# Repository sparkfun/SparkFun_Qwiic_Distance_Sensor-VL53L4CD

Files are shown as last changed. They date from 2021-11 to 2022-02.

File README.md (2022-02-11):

SparkFun Distance Sensor - VL53L4CD (Qwiic)
========================================

SparkFun Distance Sensor - VL53L4CD (Qwiic) (https://www.sparkfun.com/products/18993)

[*SparkFun Distance Sensor - VL53L4CD (Qwiic) (SEN-18993)*](https://www.sparkfun.com/products/18993)

This SparkFun Distance Sensor Breakout utilizes the VL53L4CD next generation ToF (Time of Flight) sensor module to give you the highly accurate measurements at short ranges for its size. The VL53L4CD from STMicroelectronics uses a VCSEL (Vertical Cavity Surface Emitting Laser) to emit an infrared laser to time the reflection to the target. That means that you will be able to measure the distance to an object from 1mm to 1300mm away with millimeter resolution! To make it even easier to get your readings, all communication is enacted exclusively via I<sup>2</sup>C, utilizing our handy Qwiic system so no soldering is required to connect it to the rest of your system. However, we still have broken out 0.1”-spaced pins in case you prefer to use a breadboard.

Each VL53L4CD sensor features a precision to be 1mm with an accuracy around +/-7mm (white target: 88%, indoor, no infrared) and a minimum read distance of this sensor is 1mm. The field of view for this little breakout has a typical full field of view of 18° with a read rate of up to 100Hz. Make sure to power this board appropriately since it will need 2.6V-3.5V to operate. Lastly, please be sure to remove the protective sticker on the VL53L1X before use otherwise it will, most assuredly, throw off your readings.

**Note:** This is a [CLASS 1](http://en.wikipedia.org/wiki/Laser_safety#Class_1) LASER PRODUCT CLASSIFIED IEC 60825-1 2014.

Repository Contents
-------------------

* **/Hardware** - Eagle design files (.brd, .sch)
* **/Production** - Production panel files (.brd)

Documentation
--------------
* **[Arduino Library](https://github.com/sparkfun/SparkFun_VL53L1X_Arduino_Library)** -  Arduino library for the VL53L1X and VL53L4CD.
* **[VL53L1X Python Package](https://github.com/sparkfun/Qwiic_VL53L1X_Py)** - Python package for the VL53L1X and VL53L4CD.
  * **[ReadtheDocs Documentation](https://qwiic-vl53l1x-py.readthedocs.io/en/latest/)**
* **[Hookup Guide](https://learn.sparkfun.com/tutorials/qwiic-distance-sensor-vl53l1x-vl53l4cd-hookup-guide)** - Basic hookup guide for the VL53L1X and VL53L4CD.

Product Versions
----------------
* [SEN-18993](https://www.sparkfun.com/products/18993) - Initial Release

Version History
---------------
* v1.0 - Initial Release 

License Information
-------------------

This product is _**open source**_! 

Please review the LICENSE.md file for license information. 

If you have any questions or concerns on licensing, please contact technical support on our [SparkFun forums](https://forum.sparkfun.com/viewforum.php?f=152).

Distributed as-is; no warranty is given.

- Your friends at SparkFun.

_<COLLABORATION CREDIT>_

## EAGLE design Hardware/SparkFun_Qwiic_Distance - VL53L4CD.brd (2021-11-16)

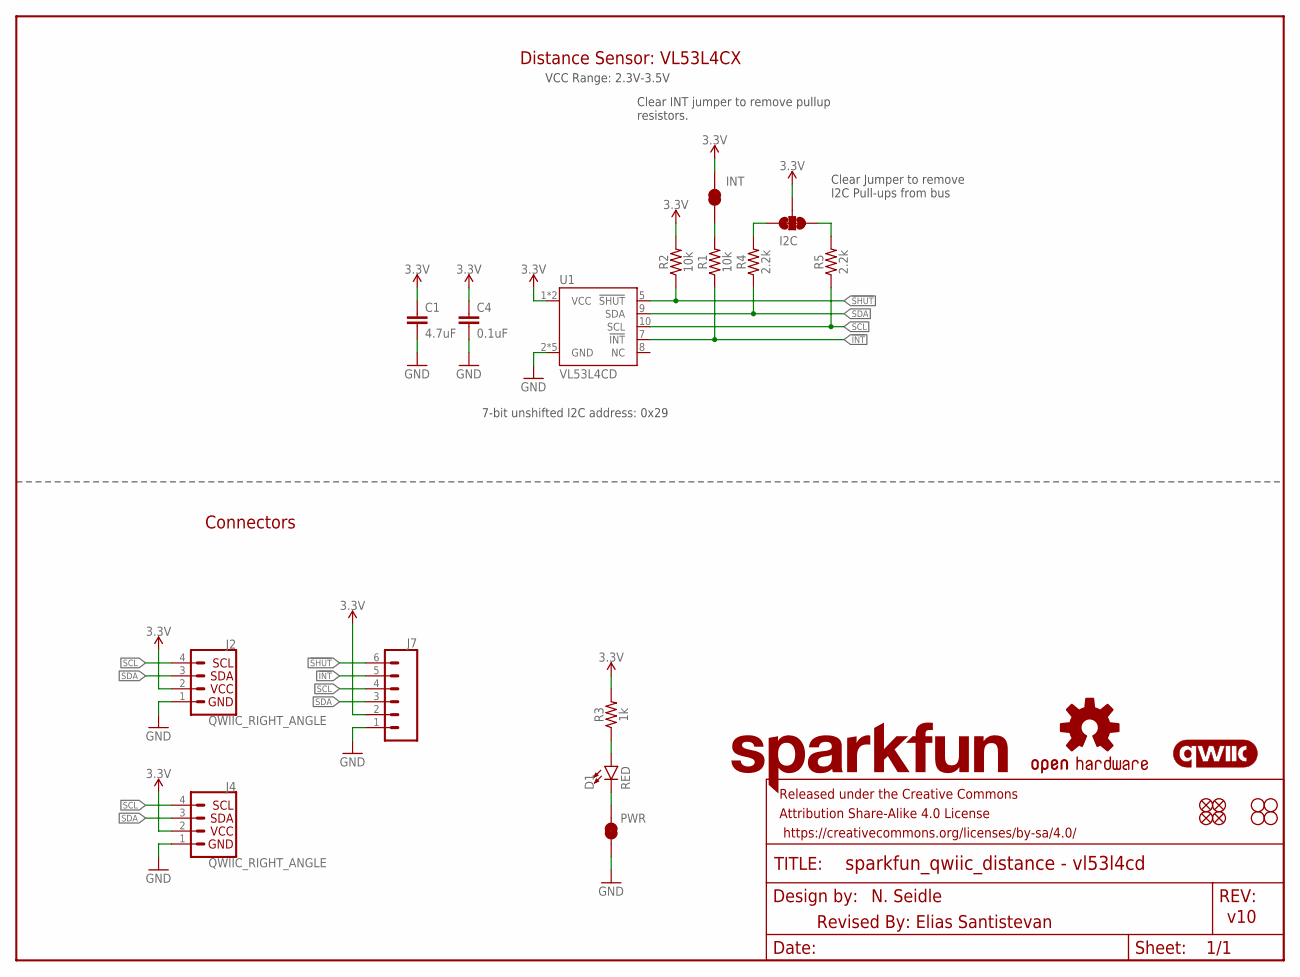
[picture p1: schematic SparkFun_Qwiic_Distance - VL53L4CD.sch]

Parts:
C1: 4.7uF; 0603
C4: 0.1uF; 0603
D1: RED; LED-0603
FRAME1: FRAME-LETTER; CREATIVE_COMMONS
I2C: JUMPER-SMT_3_2-NC_TRACE_SILK; SMT-JUMPER_3_2-NC_TRACE_SILK
J2, J4: QWIIC_RIGHT_ANGLE; JST04_1MM_RA
J7: CONN_06NO_SILK_NO_POP; 1X06_NO_SILK
JP1, JP2, JP5, JP6: FIDUCIALUFIDUCIAL; MICRO-FIDUCIAL
JP3, JP4, JP7, JP8: STAND-OFF
JP9: INT; SMT-JUMPER_2_NC_TRACE_SILK
LOGO1: OSHW-LOGOMINI; OSHW-LOGO-MINI
LOGO2: SFE_LOGO_NAME.1_INCH; SFE_LOGO_NAME_.1
LOGO3: QWIIC_LOGO_4MM; QWIIC_4MM
PWR: INT; SMT-JUMPER_2_NC_TRACE_SILK
R1, R2: 10k; 0603
R3: 1k; 0603
R4, R5: 2.2k; 0603
U1: VL53L4CD

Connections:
3.3V: C1.1, C4.1, I2C.2, J2.2, J4.2, J7.2, JP9.2, R2.2, R3.2, U1.1 (VCC), U1.11 (VCC)
!INT: J7.5, R1.1, U1.7 (!INT)
!SHUT: J7.6, R2.1, U1.5 (!SHUT)
GND: C1.2, C4.2, J2.1, J4.1, J7.1, PWR.1, U1.2 (GND), U1.3 (GND), U1.4 (GND), U1.6 (GND), U1.12 (GND)
unnamed: I2C.1, R5.2
unnamed: I2C.3, R4.2
unnamed: D1.A, R3.1
unnamed: JP9.1, R1.2
unnamed: D1.C, PWR.2
SCL: J2.4, J4.4, J7.4, R5.1, U1.10 (SCL)
SDA: J2.3, J4.3, J7.3, R4.1, U1.9 (SDA)

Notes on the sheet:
N. Seidle
v10
7-bit unshifted I2C address: 0x29
Clear Jumper to remove I2C Pull-ups from bus
Clear INT jumper to remove pullup resistors.
Connectors
Distance Sensor: VL53L4CX
VCC Range: 2.3V-3.5V
Revised By: Elias Santistevan

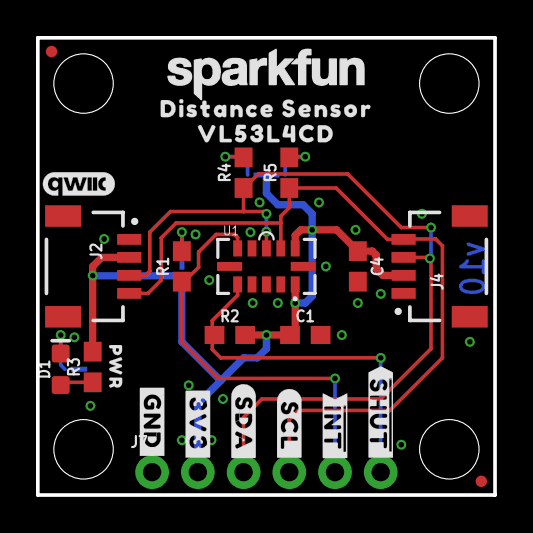
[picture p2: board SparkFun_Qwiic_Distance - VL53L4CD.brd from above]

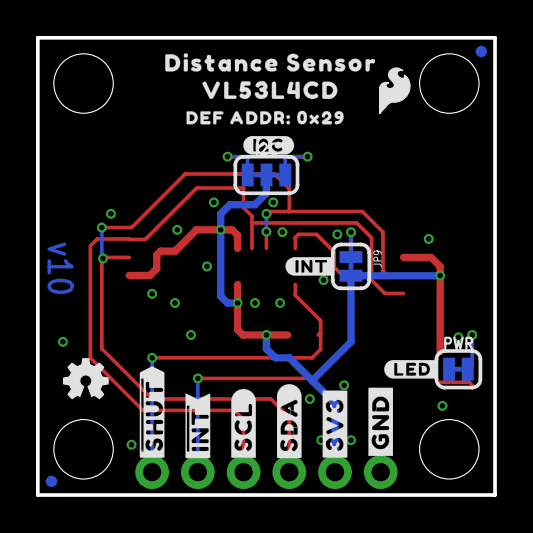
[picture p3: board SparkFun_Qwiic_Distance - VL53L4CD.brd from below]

Board: 2 copper layers, 25.4 x 25.4 mm, 50 parts (20 on the bottom side), 11 nets.

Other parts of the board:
U$1, U$12: ##INT##7
U$2, U$13: ##SHUT##6
U$3, U$14: #3V3#1
U$4, U$15: #GND#0
U$5: #I2C#56
U$6, U$16: #SCL#4
U$7, U$17: #SDA#5
U$8, U$18: DISTANCE_SENSOR8
U$9, U$24: VL53L4CD0
U$10: #LED#54
U$11: #INT#55
U$20: DEF_ADDR#54
U$21: 0X2955
U$22: SFE_LOGO_FLAME_.1
U$23: PWR55

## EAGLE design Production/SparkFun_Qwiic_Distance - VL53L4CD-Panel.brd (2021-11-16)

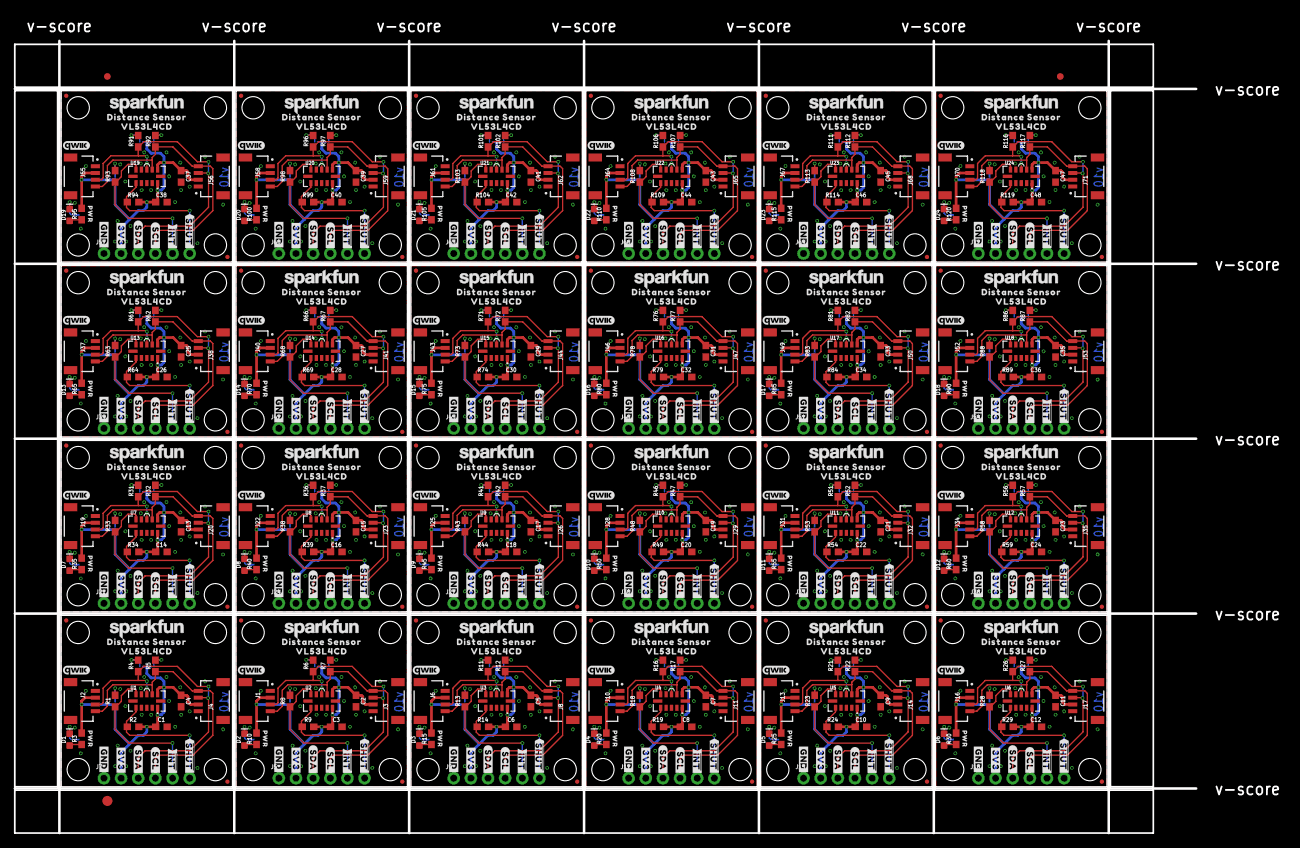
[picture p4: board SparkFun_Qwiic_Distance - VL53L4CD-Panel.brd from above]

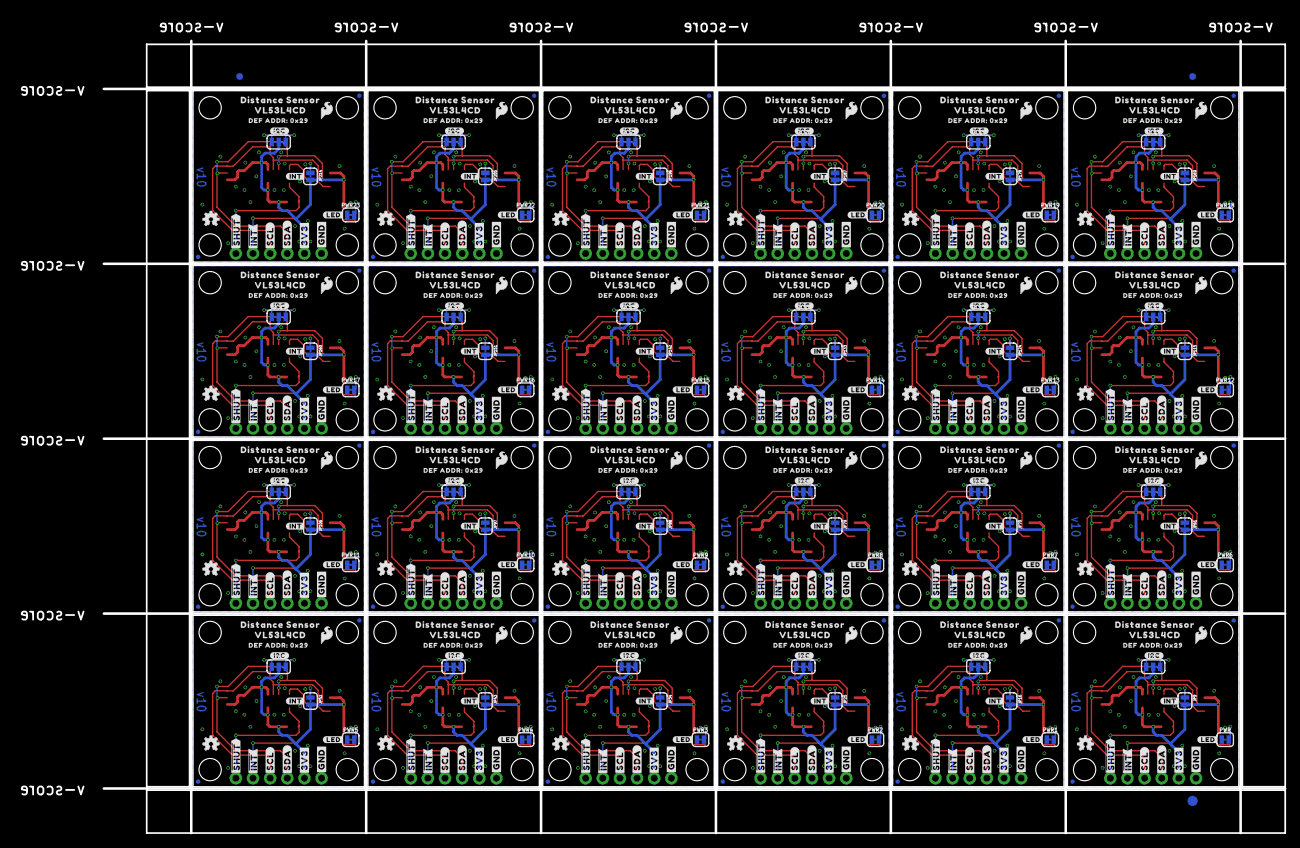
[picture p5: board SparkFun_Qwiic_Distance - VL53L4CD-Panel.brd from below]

Board: 2 copper layers, 175.0 x 117.3 mm, 1182 parts (483 on the bottom side), 264 nets.

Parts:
C1, C3, C6, C8, C10, C12, C14, C16, C18, C20, C22, C24, C26, C28, C30, C32, C34, C36, C38, C40, C42, C44, C46, C48: 4.7uF; 0603
C2, C4, C5, C7, C9, C11, C13, C15, C17, C19, C21, C23, C25, C27, C29, C31, C33, C35, C37, C39, C41, C43, C45, C47: 0.1uF; 0603
D1, D2, D3, D4, D5, D6, D7, D8, D9, D10, D11, D12, D13, D14, D15, D16, D17, D18, D19, D20, D21, D22, D23, D24: RED; LED-0603
E$1, E$2, E$3, E$4: FIDUCIAL-1X2
E$5, E$6: FIDUCIAL-1.5X3
I2C, I2C1, I2C2, I2C3, I2C4, I2C5, I2C6, I2C7, I2C8, I2C9, I2C10, I2C11, I2C12, I2C13, I2C14, I2C15, I2C16, I2C17, I2C18, I2C19, I2C20, I2C21, I2C22, I2C23: JUMPER-SMT_3_2-NC_TRACE_SILK; SMT-JUMPER_3_2-NC_TRACE_SILK
J1, J2, J3, J4, J6, J8, J10, J11, J13, J14, J16, J17, J19, J20, J22, J23, J25, J26, J28, J29, J31, J32, J34, J35, J37, J38, J40, J41, J43, J44, J46, J47, J49, J50, J52, J53, J55, J56, J58, J59, J61, J62, J64, J65, J67, J68, J70, J71: QWIIC_RIGHT_ANGLE; JST04_1MM_RA
J5, J7, J9, J12, J15, J18, J21, J24, J27, J30, J33, J36, J39, J42, J45, J48, J51, J54, J57, J60, J63, J66, J69, J72: 1X06_NO_SILK
JP1, JP2, JP5, JP6, JP12, JP13, JP14, JP15, JP21, JP22, JP23, JP24, JP30, JP31, JP32, JP33, JP39, JP40, JP41, JP42, JP48, JP49, JP50, JP51, JP57, JP58, JP59, JP60, JP66, JP67, JP68, JP69, JP75, JP76, JP77, JP78, JP84, JP85, JP86, JP87, JP93, JP94, JP95, JP96, JP102, JP103, JP104, JP105, JP111, JP112, JP113, JP114, JP120, JP121, JP122, JP123, JP129, JP130, JP131, JP132, JP138, JP139, JP140, JP141, JP147, JP148, JP149, JP150, JP156, JP157, JP158, JP159, JP165, JP166, JP167, JP168, JP174, JP175, JP176, JP177, JP183, JP184, JP185, JP186, JP192, JP193, JP194, JP195, JP201, JP202, JP203, JP204, JP210, JP211, JP212, JP213: FIDUCIALUFIDUCIAL; MICRO-FIDUCIAL
JP3, JP4, JP7, JP8, JP10, JP11, JP17, JP18, JP19, JP20, JP26, JP27, JP28, JP29, JP35, JP36, JP37, JP38, JP44, JP45, JP46, JP47, JP53, JP54, JP55, JP56, JP62, JP63, JP64, JP65, JP71, JP72, JP73, JP74, JP80, JP81, JP82, JP83, JP89, JP90, JP91, JP92, JP98, JP99, JP100, JP101, JP107, JP108, JP109, JP110, JP116, JP117, JP118, JP119, JP125, JP126, JP127, JP128, JP134, JP135, JP136, JP137, JP143, JP144, JP145, JP146, JP152, JP153, JP154, JP155, JP161, JP162, JP163, JP164, JP170, JP171, JP172, JP173, JP179, JP180, JP181, JP182, JP188, JP189, JP190, JP191, JP197, JP198, JP199, JP200, JP206, JP207, JP208, JP209, JP215, JP216: STAND-OFF
JP9, JP16, JP25, JP34, JP43, JP52, JP61, JP70, JP79, JP88, JP97, JP106, JP115, JP124, JP133, JP142, JP151, JP160, JP169, JP178, JP187, JP196, JP205, JP214: INT; SMT-JUMPER_2_NC_TRACE_SILK
LOGO1, LOGO4, LOGO7, LOGO10, LOGO13, LOGO16, LOGO19, LOGO22, LOGO25, LOGO28, LOGO31, LOGO34, LOGO37, LOGO40, LOGO43, LOGO46, LOGO49, LOGO52, LOGO55, LOGO58, LOGO61, LOGO64, LOGO67, LOGO70: OSHW-LOGOMINI; OSHW-LOGO-MINI
LOGO2, LOGO5, LOGO8, LOGO11, LOGO14, LOGO17, LOGO20, LOGO23, LOGO26, LOGO29, LOGO32, LOGO35, LOGO38, LOGO41, LOGO44, LOGO47, LOGO50, LOGO53, LOGO56, LOGO59, LOGO62, LOGO65, LOGO68, LOGO71: SFE_LOGO_NAME.1_INCH; SFE_LOGO_NAME_.1
LOGO3, LOGO6, LOGO9, LOGO12, LOGO15, LOGO18, LOGO21, LOGO24, LOGO27, LOGO30, LOGO33, LOGO36, LOGO39, LOGO42, LOGO45, LOGO48, LOGO51, LOGO54, LOGO57, LOGO60, LOGO63, LOGO66, LOGO69, LOGO72: QWIIC_LOGO_4MM; QWIIC_4MM
PWR, PWR1, PWR2, PWR3, PWR4, PWR5, PWR6, PWR7, PWR8, PWR9, PWR10, PWR11, PWR12, PWR13, PWR14, PWR15, PWR16, PWR17, PWR18, PWR19, PWR20, PWR21, PWR22, PWR23: INT; SMT-JUMPER_2_NC_TRACE_SILK
R1, R2, R8, R9, R13, R14, R18, R19, R23, R24, R28, R29, R33, R34, R38, R39, R43, R44, R48, R49, R53, R54, R58, R59, R63, R64, R68, R69, R73, R74, R78, R79, R83, R84, R88, R89, R93, R94, R98, R99, R103, R104, R108, R109, R113, R114, R118, R119: 10k; 0603
R3, R10, R15, R20, R25, R30, R35, R40, R45, R50, R55, R60, R65, R70, R75, R80, R85, R90, R95, R100, R105, R110, R115, R120: 1k; 0603
R4, R5, R6, R7, R11, R12, R16, R17, R21, R22, R26, R27, R31, R32, R36, R37, R41, R42, R46, R47, R51, R52, R56, R57, R61, R62, R66, R67, R71, R72, R76, R77, R81, R82, R86, R87, R91, R92, R96, R97, R101, R102, R106, R107, R111, R112, R116, R117: 2.2k; 0603
U1, U2, U3, U4, U5, U6, U7, U8, U9, U10, U11, U12, U13, U14, U15, U16, U17, U18, U19, U20, U21, U22, U23, U24: VL53L4CX
U$1, U$12, U$19, U$34, U$47, U$57, U$70, U$80, U$93, U$103, U$116, U$126, U$139, U$149, U$162, U$172, U$185, U$195, U$208, U$218, U$231, U$241, U$254, U$264, U$277, U$287, U$300, U$310, U$323, U$333, U$346, U$356, U$369, U$379, U$392, U$402, U$415, U$425, U$438, U$448, U$461, U$471, U$484, U$494, U$507, U$517, U$530, U$540: ##INT##7
U$2, U$13, U$25, U$35, U$48, U$58, U$71, U$81, U$94, U$104, U$117, U$127, U$140, U$150, U$163, U$173, U$186, U$196, U$209, U$219, U$232, U$242, U$255, U$265, U$278, U$288, U$301, U$311, U$324, U$334, U$347, U$357, U$370, U$380, U$393, U$403, U$416, U$426, U$439, U$449, U$462, U$472, U$485, U$495, U$508, U$518, U$531, U$541: ##SHUT##6
U$3, U$14, U$26, U$36, U$49, U$59, U$72, U$82, U$95, U$105, U$118, U$128, U$141, U$151, U$164, U$174, U$187, U$197, U$210, U$220, U$233, U$243, U$256, U$266, U$279, U$289, U$302, U$312, U$325, U$335, U$348, U$358, U$371, U$381, U$394, U$404, U$417, U$427, U$440, U$450, U$463, U$473, U$486, U$496, U$509, U$519, U$532, U$542: #3V3#1
U$4, U$15, U$27, U$37, U$50, U$60, U$73, U$83, U$96, U$106, U$119, U$129, U$142, U$152, U$165, U$175, U$188, U$198, U$211, U$221, U$234, U$244, U$257, U$267, U$280, U$290, U$303, U$313, U$326, U$336, U$349, U$359, U$372, U$382, U$395, U$405, U$418, U$428, U$441, U$451, U$464, U$474, U$487, U$497, U$510, U$520, U$533, U$543: #GND#0
U$5, U$28, U$51, U$74, U$97, U$120, U$143, U$166, U$189, U$212, U$235, U$258, U$281, U$304, U$327, U$350, U$373, U$396, U$419, U$442, U$465, U$488, U$511, U$534: #I2C#56
U$6, U$16, U$29, U$38, U$52, U$61, U$75, U$84, U$98, U$107, U$121, U$130, U$144, U$153, U$167, U$176, U$190, U$199, U$213, U$222, U$236, U$245, U$259, U$268, U$282, U$291, U$305, U$314, U$328, U$337, U$351, U$360, U$374, U$383, U$397, U$406, U$420, U$429, U$443, U$452, U$466, U$475, U$489, U$498, U$512, U$521, U$535, U$544: #SCL#4
U$7, U$17, U$30, U$39, U$53, U$62, U$76, U$85, U$99, U$108, U$122, U$131, U$145, U$154, U$168, U$177, U$191, U$200, U$214, U$223, U$237, U$246, U$260, U$269, U$283, U$292, U$306, U$315, U$329, U$338, U$352, U$361, U$375, U$384, U$398, U$407, U$421, U$430, U$444, U$453, U$467, U$476, U$490, U$499, U$513, U$522, U$536, U$545: #SDA#5
U$8, U$18, U$31, U$40, U$54, U$63, U$77, U$86, U$100, U$109, U$123, U$132, U$146, U$155, U$169, U$178, U$192, U$201, U$215, U$224, U$238, U$247, U$261, U$270, U$284, U$293, U$307, U$316, U$330, U$339, U$353, U$362, U$376, U$385, U$399, U$408, U$422, U$431, U$445, U$454, U$468, U$477, U$491, U$500, U$514, U$523, U$537, U$546: DISTANCE_SENSOR8
U$9, U$24, U$45, U$46, U$68, U$69, U$91, U$92, U$114, U$115, U$137, U$138, U$160, U$161, U$183, U$184, U$206, U$207, U$229, U$230, U$252, U$253, U$275, U$276, U$298, U$299, U$321, U$322, U$344, U$345, U$367, U$368, U$390, U$391, U$413, U$414, U$436, U$437, U$459, U$460, U$482, U$483, U$505, U$506, U$528, U$529, U$551, U$552: VL53L4CD0
U$10, U$32, U$55, U$78, U$101, U$124, U$147, U$170, U$193, U$216, U$239, U$262, U$285, U$308, U$331, U$354, U$377, U$400, U$423, U$446, U$469, U$492, U$515, U$538: #LED#54
U$11, U$33, U$56, U$79, U$102, U$125, U$148, U$171, U$194, U$217, U$240, U$263, U$286, U$309, U$332, U$355, U$378, U$401, U$424, U$447, U$470, U$493, U$516, U$539: #INT#55
U$20, U$41, U$64, U$87, U$110, U$133, U$156, U$179, U$202, U$225, U$248, U$271, U$294, U$317, U$340, U$363, U$386, U$409, U$432, U$455, U$478, U$501, U$524, U$547: DEF_ADDR#54
U$21, U$42, U$65, U$88, U$111, U$134, U$157, U$180, U$203, U$226, U$249, U$272, U$295, U$318, U$341, U$364, U$387, U$410, U$433, U$456, U$479, U$502, U$525, U$548: 0X2955
U$22, U$43, U$66, U$89, U$112, U$135, U$158, U$181, U$204, U$227, U$250, U$273, U$296, U$319, U$342, U$365, U$388, U$411, U$434, U$457, U$480, U$503, U$526, U$549: SFE_LOGO_FLAME_.1
U$23, U$44, U$67, U$90, U$113, U$136, U$159, U$182, U$205, U$228, U$251, U$274, U$297, U$320, U$343, U$366, U$389, U$412, U$435, U$458, U$481, U$504, U$527, U$550: PWR55

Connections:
3.3V: C1.1, C4.1, I2C.2, J2.2, J4.2, J7.2, JP9.2, R2.2, R3.2, U1.1, U1.11
3.3V1: C2.1, C3.1, I2C1.2, J1.2, J3.2, J5.2, JP16.2, R9.2, R10.2, U2.1, U2.11
3.3V2: C5.1, C6.1, I2C2.2, J6.2, J8.2, J9.2, JP25.2, R14.2, R15.2, U3.1, U3.11
3.3V3: C7.1, C8.1, I2C3.2, J10.2, J11.2, J12.2, JP34.2, R19.2, R20.2, U4.1, U4.11
3.3V4: C9.1, C10.1, I2C4.2, J13.2, J14.2, J15.2, JP43.2, R24.2, R25.2, U5.1, U5.11
3.3V5: C11.1, C12.1, I2C5.2, J16.2, J17.2, J18.2, JP52.2, R29.2, R30.2, U6.1, U6.11
3.3V6: C13.1, C14.1, I2C6.2, J19.2, J20.2, J21.2, JP61.2, R34.2, R35.2, U7.1, U7.11
3.3V7: C15.1, C16.1, I2C7.2, J22.2, J23.2, J24.2, JP70.2, R39.2, R40.2, U8.1, U8.11
3.3V8: C17.1, C18.1, I2C8.2, J25.2, J26.2, J27.2, JP79.2, R44.2, R45.2, U9.1, U9.11
3.3V9: C19.1, C20.1, I2C9.2, J28.2, J29.2, J30.2, JP88.2, R49.2, R50.2, U10.1, U10.11
3.3V10: C21.1, C22.1, I2C10.2, J31.2, J32.2, J33.2, JP97.2, R54.2, R55.2, U11.1, U11.11
3.3V11: C23.1, C24.1, I2C11.2, J34.2, J35.2, J36.2, JP106.2, R59.2, R60.2, U12.1, U12.11
3.3V12: C25.1, C26.1, I2C12.2, J37.2, J38.2, J39.2, JP115.2, R64.2, R65.2, U13.1, U13.11
3.3V13: C27.1, C28.1, I2C13.2, J40.2, J41.2, J42.2, JP124.2, R69.2, R70.2, U14.1, U14.11
3.3V14: C29.1, C30.1, I2C14.2, J43.2, J44.2, J45.2, JP133.2, R74.2, R75.2, U15.1, U15.11
3.3V15: C31.1, C32.1, I2C15.2, J46.2, J47.2, J48.2, JP142.2, R79.2, R80.2, U16.1, U16.11
3.3V16: C33.1, C34.1, I2C16.2, J49.2, J50.2, J51.2, JP151.2, R84.2, R85.2, U17.1, U17.11
3.3V17: C35.1, C36.1, I2C17.2, J52.2, J53.2, J54.2, JP160.2, R89.2, R90.2, U18.1, U18.11
3.3V18: C37.1, C38.1, I2C18.2, J55.2, J56.2, J57.2, JP169.2, R94.2, R95.2, U19.1, U19.11
3.3V19: C39.1, C40.1, I2C19.2, J58.2, J59.2, J60.2, JP178.2, R99.2, R100.2, U20.1, U20.11
3.3V20: C41.1, C42.1, I2C20.2, J61.2, J62.2, J63.2, JP187.2, R104.2, R105.2, U21.1, U21.11
3.3V21: C43.1, C44.1, I2C21.2, J64.2, J65.2, J66.2, JP196.2, R109.2, R110.2, U22.1, U22.11
3.3V22: C45.1, C46.1, I2C22.2, J67.2, J68.2, J69.2, JP205.2, R114.2, R115.2, U23.1, U23.11
3.3V23: C47.1, C48.1, I2C23.2, J70.2, J71.2, J72.2, JP214.2, R119.2, R120.2, U24.1, U24.11
!INT: J7.5, R1.1, U1.7
!INT1: J5.5, R8.1, U2.7
!INT2: J9.5, R13.1, U3.7
!INT3: J12.5, R18.1, U4.7
!INT4: J15.5, R23.1, U5.7
!INT5: J18.5, R28.1, U6.7
!INT6: J21.5, R33.1, U7.7
!INT7: J24.5, R38.1, U8.7
!INT8: J27.5, R43.1, U9.7
!INT9: J30.5, R48.1, U10.7
!INT10: J33.5, R53.1, U11.7
!INT11: J36.5, R58.1, U12.7
!INT12: J39.5, R63.1, U13.7
!INT13: J42.5, R68.1, U14.7
!INT14: J45.5, R73.1, U15.7
!INT15: J48.5, R78.1, U16.7
!INT16: J51.5, R83.1, U17.7
!INT17: J54.5, R88.1, U18.7
!INT18: J57.5, R93.1, U19.7
!INT19: J60.5, R98.1, U20.7
!INT20: J63.5, R103.1, U21.7
!INT21: J66.5, R108.1, U22.7
!INT22: J69.5, R113.1, U23.7
!INT23: J72.5, R118.1, U24.7
!SHUT: J7.6, R2.1, U1.5
!SHUT1: J5.6, R9.1, U2.5
!SHUT2: J9.6, R14.1, U3.5
!SHUT3: J12.6, R19.1, U4.5
!SHUT4: J15.6, R24.1, U5.5
!SHUT5: J18.6, R29.1, U6.5
!SHUT6: J21.6, R34.1, U7.5
!SHUT7: J24.6, R39.1, U8.5
!SHUT8: J27.6, R44.1, U9.5
!SHUT9: J30.6, R49.1, U10.5
!SHUT10: J33.6, R54.1, U11.5
!SHUT11: J36.6, R59.1, U12.5
!SHUT12: J39.6, R64.1, U13.5
!SHUT13: J42.6, R69.1, U14.5
!SHUT14: J45.6, R74.1, U15.5
!SHUT15: J48.6, R79.1, U16.5
!SHUT16: J51.6, R84.1, U17.5
!SHUT17: J54.6, R89.1, U18.5
!SHUT18: J57.6, R94.1, U19.5
!SHUT19: J60.6, R99.1, U20.5
!SHUT20: J63.6, R104.1, U21.5
!SHUT21: J66.6, R109.1, U22.5
!SHUT22: J69.6, R114.1, U23.5
!SHUT23: J72.6, R119.1, U24.5
GND: C1.2, C4.2, J2.1, J4.1, J7.1, PWR.1, U1.2, U1.3, U1.4, U1.6, U1.12
GND1: C2.2, C3.2, J1.1, J3.1, J5.1, PWR1.1, U2.2, U2.3, U2.4, U2.6, U2.12
GND2: C5.2, C6.2, J6.1, J8.1, J9.1, PWR2.1, U3.2, U3.3, U3.4, U3.6, U3.12
GND3: C7.2, C8.2, J10.1, J11.1, J12.1, PWR3.1, U4.2, U4.3, U4.4, U4.6, U4.12
GND4: C9.2, C10.2, J13.1, J14.1, J15.1, PWR4.1, U5.2, U5.3, U5.4, U5.6, U5.12
GND5: C11.2, C12.2, J16.1, J17.1, J18.1, PWR5.1, U6.2, U6.3, U6.4, U6.6, U6.12
GND6: C13.2, C14.2, J19.1, J20.1, J21.1, PWR6.1, U7.2, U7.3, U7.4, U7.6, U7.12
GND7: C15.2, C16.2, J22.1, J23.1, J24.1, PWR7.1, U8.2, U8.3, U8.4, U8.6, U8.12
GND8: C17.2, C18.2, J25.1, J26.1, J27.1, PWR8.1, U9.2, U9.3, U9.4, U9.6, U9.12
GND9: C19.2, C20.2, J28.1, J29.1, J30.1, PWR9.1, U10.2, U10.3, U10.4, U10.6, U10.12
GND10: C21.2, C22.2, J31.1, J32.1, J33.1, PWR10.1, U11.2, U11.3, U11.4, U11.6, U11.12
GND11: C23.2, C24.2, J34.1, J35.1, J36.1, PWR11.1, U12.2, U12.3, U12.4, U12.6, U12.12
GND12: C25.2, C26.2, J37.1, J38.1, J39.1, PWR12.1, U13.2, U13.3, U13.4, U13.6, U13.12
GND13: C27.2, C28.2, J40.1, J41.1, J42.1, PWR13.1, U14.2, U14.3, U14.4, U14.6, U14.12
GND14: C29.2, C30.2, J43.1, J44.1, J45.1, PWR14.1, U15.2, U15.3, U15.4, U15.6, U15.12
GND15: C31.2, C32.2, J46.1, J47.1, J48.1, PWR15.1, U16.2, U16.3, U16.4, U16.6, U16.12
GND16: C33.2, C34.2, J49.1, J50.1, J51.1, PWR16.1, U17.2, U17.3, U17.4, U17.6, U17.12
GND17: C35.2, C36.2, J52.1, J53.1, J54.1, PWR17.1, U18.2, U18.3, U18.4, U18.6, U18.12
GND18: C37.2, C38.2, J55.1, J56.1, J57.1, PWR18.1, U19.2, U19.3, U19.4, U19.6, U19.12
GND19: C39.2, C40.2, J58.1, J59.1, J60.1, PWR19.1, U20.2, U20.3, U20.4, U20.6, U20.12
GND20: C41.2, C42.2, J61.1, J62.1, J63.1, PWR20.1, U21.2, U21.3, U21.4, U21.6, U21.12
GND21: C43.2, C44.2, J64.1, J65.1, J66.1, PWR21.1, U22.2, U22.3, U22.4, U22.6, U22.12
GND22: C45.2, C46.2, J67.1, J68.1, J69.1, PWR22.1, U23.2, U23.3, U23.4, U23.6, U23.12
GND23: C47.2, C48.2, J70.1, J71.1, J72.1, PWR23.1, U24.2, U24.3, U24.4, U24.6, U24.12
unnamed: I2C.1, R5.2
unnamed: I2C.3, R4.2
unnamed: D1.A, R3.1
unnamed: JP9.1, R1.2
unnamed: D1.C, PWR.2
unnamed: I2C1.1, R7.2
unnamed: I2C1.3, R6.2
unnamed: JP16.1, R8.2
unnamed: D2.A, R10.1
unnamed: D2.C, PWR1.2
unnamed: I2C2.1, R12.2
unnamed: I2C2.3, R11.2
unnamed: JP25.1, R13.2
unnamed: D3.A, R15.1
unnamed: D3.C, PWR2.2
unnamed: I2C3.1, R17.2
unnamed: I2C3.3, R16.2
unnamed: JP34.1, R18.2
unnamed: D4.A, R20.1
unnamed: D4.C, PWR3.2
unnamed: I2C4.1, R22.2
unnamed: I2C4.3, R21.2
unnamed: JP43.1, R23.2
unnamed: D5.A, R25.1
unnamed: D5.C, PWR4.2
unnamed: I2C5.1, R27.2
unnamed: I2C5.3, R26.2
unnamed: JP52.1, R28.2
unnamed: D6.A, R30.1
unnamed: D6.C, PWR5.2
unnamed: I2C6.1, R32.2
unnamed: I2C6.3, R31.2
unnamed: JP61.1, R33.2
unnamed: D7.A, R35.1
unnamed: D7.C, PWR6.2
unnamed: I2C7.1, R37.2
unnamed: I2C7.3, R36.2
unnamed: JP70.1, R38.2
unnamed: D8.A, R40.1
unnamed: D8.C, PWR7.2
unnamed: I2C8.1, R42.2
unnamed: I2C8.3, R41.2
unnamed: JP79.1, R43.2
unnamed: D9.A, R45.1
unnamed: D9.C, PWR8.2
unnamed: I2C9.1, R47.2
unnamed: I2C9.3, R46.2
unnamed: JP88.1, R48.2
unnamed: D10.A, R50.1
unnamed: D10.C, PWR9.2
unnamed: I2C10.1, R52.2
unnamed: I2C10.3, R51.2
unnamed: JP97.1, R53.2
unnamed: D11.A, R55.1
unnamed: D11.C, PWR10.2
unnamed: I2C11.1, R57.2
unnamed: I2C11.3, R56.2
unnamed: JP106.1, R58.2
unnamed: D12.A, R60.1
unnamed: D12.C, PWR11.2
unnamed: I2C12.1, R62.2
unnamed: I2C12.3, R61.2
unnamed: JP115.1, R63.2
unnamed: D13.A, R65.1
unnamed: D13.C, PWR12.2
unnamed: I2C13.1, R67.2
unnamed: I2C13.3, R66.2
unnamed: JP124.1, R68.2
unnamed: D14.A, R70.1
unnamed: D14.C, PWR13.2
unnamed: I2C14.1, R72.2
unnamed: I2C14.3, R71.2
unnamed: JP133.1, R73.2
unnamed: D15.A, R75.1
unnamed: D15.C, PWR14.2
unnamed: I2C15.1, R77.2
unnamed: I2C15.3, R76.2
unnamed: JP142.1, R78.2
unnamed: D16.A, R80.1
unnamed: D16.C, PWR15.2
unnamed: I2C16.1, R82.2
unnamed: I2C16.3, R81.2
unnamed: JP151.1, R83.2
unnamed: D17.A, R85.1
unnamed: D17.C, PWR16.2
unnamed: I2C17.1, R87.2
unnamed: I2C17.3, R86.2
unnamed: JP160.1, R88.2
unnamed: D18.A, R90.1
unnamed: D18.C, PWR17.2
unnamed: I2C18.1, R92.2
unnamed: I2C18.3, R91.2
unnamed: JP169.1, R93.2
unnamed: D19.A, R95.1
unnamed: D19.C, PWR18.2
unnamed: I2C19.1, R97.2
unnamed: I2C19.3, R96.2
unnamed: JP178.1, R98.2
unnamed: D20.A, R100.1
unnamed: D20.C, PWR19.2
unnamed: I2C20.1, R102.2
unnamed: I2C20.3, R101.2
unnamed: JP187.1, R103.2
unnamed: D21.A, R105.1
unnamed: D21.C, PWR20.2
unnamed: I2C21.1, R107.2
unnamed: I2C21.3, R106.2
unnamed: JP196.1, R108.2
unnamed: D22.A, R110.1
unnamed: D22.C, PWR21.2
unnamed: I2C22.1, R112.2
unnamed: I2C22.3, R111.2
unnamed: JP205.1, R113.2
unnamed: D23.A, R115.1
unnamed: D23.C, PWR22.2
unnamed: I2C23.1, R117.2
unnamed: I2C23.3, R116.2
unnamed: JP214.1, R118.2
unnamed: D24.A, R120.1
unnamed: D24.C, PWR23.2
SCL: J2.4, J4.4, J7.4, R5.1, U1.10
SCL1: J1.4, J3.4, J5.4, R7.1, U2.10
SCL2: J6.4, J8.4, J9.4, R12.1, U3.10
SCL3: J10.4, J11.4, J12.4, R17.1, U4.10
SCL4: J13.4, J14.4, J15.4, R22.1, U5.10
SCL5: J16.4, J17.4, J18.4, R27.1, U6.10
SCL6: J19.4, J20.4, J21.4, R32.1, U7.10
SCL7: J22.4, J23.4, J24.4, R37.1, U8.10
SCL8: J25.4, J26.4, J27.4, R42.1, U9.10
SCL9: J28.4, J29.4, J30.4, R47.1, U10.10
SCL10: J31.4, J32.4, J33.4, R52.1, U11.10
SCL11: J34.4, J35.4, J36.4, R57.1, U12.10
SCL12: J37.4, J38.4, J39.4, R62.1, U13.10
SCL13: J40.4, J41.4, J42.4, R67.1, U14.10
SCL14: J43.4, J44.4, J45.4, R72.1, U15.10
SCL15: J46.4, J47.4, J48.4, R77.1, U16.10
SCL16: J49.4, J50.4, J51.4, R82.1, U17.10
SCL17: J52.4, J53.4, J54.4, R87.1, U18.10
SCL18: J55.4, J56.4, J57.4, R92.1, U19.10
SCL19: J58.4, J59.4, J60.4, R97.1, U20.10
SCL20: J61.4, J62.4, J63.4, R102.1, U21.10
SCL21: J64.4, J65.4, J66.4, R107.1, U22.10
SCL22: J67.4, J68.4, J69.4, R112.1, U23.10
SCL23: J70.4, J71.4, J72.4, R117.1, U24.10
SDA: J2.3, J4.3, J7.3, R4.1, U1.9
SDA1: J1.3, J3.3, J5.3, R6.1, U2.9
SDA2: J6.3, J8.3, J9.3, R11.1, U3.9
SDA3: J10.3, J11.3, J12.3, R16.1, U4.9
SDA4: J13.3, J14.3, J15.3, R21.1, U5.9
SDA5: J16.3, J17.3, J18.3, R26.1, U6.9
SDA6: J19.3, J20.3, J21.3, R31.1, U7.9
SDA7: J22.3, J23.3, J24.3, R36.1, U8.9
SDA8: J25.3, J26.3, J27.3, R41.1, U9.9
SDA9: J28.3, J29.3, J30.3, R46.1, U10.9
SDA10: J31.3, J32.3, J33.3, R51.1, U11.9
SDA11: J34.3, J35.3, J36.3, R56.1, U12.9
SDA12: J37.3, J38.3, J39.3, R61.1, U13.9
SDA13: J40.3, J41.3, J42.3, R66.1, U14.9
SDA14: J43.3, J44.3, J45.3, R71.1, U15.9
SDA15: J46.3, J47.3, J48.3, R76.1, U16.9
SDA16: J49.3, J50.3, J51.3, R81.1, U17.9
SDA17: J52.3, J53.3, J54.3, R86.1, U18.9
SDA18: J55.3, J56.3, J57.3, R91.1, U19.9
SDA19: J58.3, J59.3, J60.3, R96.1, U20.9
SDA20: J61.3, J62.3, J63.3, R101.1, U21.9
SDA21: J64.3, J65.3, J66.3, R106.1, U22.9
SDA22: J67.3, J68.3, J69.3, R111.1, U23.9
SDA23: J70.3, J71.3, J72.3, R116.1, U24.9

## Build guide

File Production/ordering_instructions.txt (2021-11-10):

panel size, 169x117mm
PCB thickness, 1.6mm
number of layers, 2
soldermask color, Red
silkscreen color, White
oz copper, 1oz
finish, HASL lead free
stencils, top
pcs per panel, 24
min trace width, 0.2032mm / 0.0080in
min drill size, 0.3048mm / 0.0120in

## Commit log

2021-11-05 Adds silk to the product
    [SparkFun_Qwiic_Distance - VL53L4CX.brd, SparkFun_Qwiic_Distance - VL53L4CX.sch]
2021-11-05 Replaces INT silk with OUTPUT style flag, adds revised by to attribution in board
    * 3.3V traces bumped to 16mils
    * Moves some silk to keep them from touching
    * Adds PWR silk
    * Adjusts some overlapping part labels
    * Corrects distance sensor name in library
    [SparkFun_Qwiic_Distance - VL53L4CX.brd, SparkFun_Qwiic_Distance - VL53L4CX.sch]
2021-11-10 Adds one via
    [SparkFun_Qwiic_Distance - VL53L4CX.brd]
2021-11-10 Adds Production Files
    [SparkFun_Qwiic_Distance - VL53L4CX-Panel.GBL, SparkFun_Qwiic_Distance - VL53L4CX-Panel.GBO, SparkFun_Qwiic_Distance - VL53L4CX-Panel.GBP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]
2021-11-10 Adds PROD_ID to distance sensor
    [SparkFun_Qwiic_Distance - VL53L4CX.brd, SparkFun_Qwiic_Distance - VL53L4CX.sch]
2021-11-16 Corrects part name, and changes eagle file names to reflect the change.
    [SparkFun_Qwiic_Distance - VL53L4CD.brd, SparkFun_Qwiic_Distance - VL53L4CD.sch]
2021-11-16 Adds new panel with corrected name
    [SparkFun_Qwiic_Distance - VL53L4CD-Panel.GBL, SparkFun_Qwiic_Distance - VL53L4CD-Panel.GBO, SparkFun_Qwiic_Distance - VL53L4CD-Panel.GBP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]
2021-11-16 Removes old production files
    [SparkFun_Qwiic_Distance - VL53L4CX-Panel.GBL, SparkFun_Qwiic_Distance - VL53L4CX-Panel.GBO, SparkFun_Qwiic_Distance - VL53L4CX-Panel.GBP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]
2021-11-16 Updates Distance Sensor Part name
    [SparkFun_Qwiic_Distance - VL53L4CD.brd, SparkFun_Qwiic_Distance - VL53L4CD.sch]

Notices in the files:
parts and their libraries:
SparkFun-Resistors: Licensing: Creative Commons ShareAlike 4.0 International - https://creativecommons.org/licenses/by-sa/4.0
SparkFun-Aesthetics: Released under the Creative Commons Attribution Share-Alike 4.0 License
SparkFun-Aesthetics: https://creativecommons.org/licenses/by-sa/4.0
